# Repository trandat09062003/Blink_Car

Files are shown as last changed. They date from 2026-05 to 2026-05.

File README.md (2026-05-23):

# 🚨 Hộp Đen Giám Sát An Toàn Xe Điện (AI TinyML & Blynk IoT)

Dự án nghiên cứu khoa học kỹ thuật xuất sắc, tích hợp Trí tuệ nhân tạo biên cục bộ (Edge AI/TinyML) sử dụng mô hình 1D-CNN và Nền tảng điều khiển IoT Blynk nhằm giám sát hành trình, phát hiện hành vi lái xe loạng choạng nguy hiểm và cảnh báo đổ ngã, tai nạn khẩn cấp theo thời gian thực.

---

## 🌟 Tính Năng Nổi Bật của Hệ Thống

1. **Phát hiện Hành vi Lạng Lách / Loạng Choạng bằng AI TinyML:**
   - Sử dụng mạng nơ-ron tích chập 1 chiều (1D-CNN) chạy suy luận offline trực tiếp trên ESP32 thông qua TensorFlow Lite Micro.
   - Cảm nhận gia tốc và góc quay 6 trục tần số 50Hz, xử lý qua cửa sổ trượt 2.0 giây để nhận diện chính xác hành vi mất lái nguy hiểm.

2. **Thuật toán Đổ Ngã Xe Thông Minh (Anti-Alarm False):**
   - Sự cố tai nạn/ngã xe chỉ được kích hoạt khi thỏa mãn đồng thời hai điều kiện:
     1. Người lái có dấu hiệu **loạng choạng/lạng lách liên tục từ 5 đến 10 giây** ngay trước đó.
     2. Xe bị **nghiêng đột ngột quá 60 độ** (góc Roll/Pitch) và **nằm im bất động (đứng im)** liên tục trong **3 giây**.
   - Thiết kế dạng máy trạng thái không chặn (Non-blocking State Machine) giúp còi hú cứu nạn kêu gọi tại chỗ đồng thời gửi định vị cứu trợ.

3. **Tích hợp IoT Blynk Platform thời gian thực:**
   - **V1 (Slider):** Đồng bộ cấu hình và điều chỉnh ngưỡng xác nhạy TinyML động từ ứng dụng di động.
   - **V2 (Value Display):** Hiển thị xác suất loạng choạng thời gian thực với độ chính xác 4 chữ số thập phân (`String(confidence, 4)`).
   - **V3 (Map):** Tự động gửi link Google Maps định vị vệ tinh GPS cứu trợ khẩn cấp thông qua thông báo Blynk Event `accident` (Critical Push Notification).

4. **Hiển thị Telemetry lên Màn hình LCD 2004 I2C:**
   - Cập nhật thời gian thực: Tốc độ xe (GPS), Xác suất AI (%), Ngưỡng Blynk (%), Số lượng vệ tinh bắt được, Trạng thái kết nối thẻ nhớ SD.

5. **Ghi Hành trình vào Thẻ nhớ MicroSD:**
   - Hỗ trợ lưu trữ dữ liệu thô (.CSV) tần số 50Hz để làm nguyên liệu huấn luyện mô hình AI mới.

6. **Deep Sleep Quản lý Năng lượng Thông minh:**
   - Hệ thống tự động đi vào giấc ngủ sâu (Deep Sleep) khi xe đứng yên quá 10 phút. ESP32 sẽ thức giấc định kỳ 5 giây để kiểm tra rung động (dắt xe/nổ máy) qua MPU6050, nếu có rung động sẽ tự khởi động lại toàn bộ hệ thống.

---

## 📐 Sơ Đồ Nối Chân Phần Cứng (GPIO Mapping)

Mạch điện được thiết kế khớp hoàn hảo với Altium Designer PCB chuyên dụng cho vi điều khiển ESP32 DEVKIT V1:

| Module Ngoại Vi | Chân Ngoại Vi | Chân GPIO trên ESP32 | Mô Tả Ý Nghĩa |
| :--- | :--- | :--- | :--- |
| **MPU6050 (IMU)** | SDA | **GPIO 21** | Đường truyền dữ liệu I2C |
| | SCL | **GPIO 22** | Đường truyền xung nhịp I2C |
| **LCD 2004 (I2C)** | SDA | **GPIO 21** | Chia sẻ bus dữ liệu I2C |
| | SCL | **GPIO 22** | Chia sẻ bus xung nhịp I2C |
| **MicroSD Card (SPI)** | CS | **GPIO 5** | Chân chọn chip SPI (Chip Select) |
| | SCK | **GPIO 18** | Chân xung nhịp SPI |
| | MISO | **GPIO 19** | Chân truyền Master Input Slave Output |
| | MOSI | **GPIO 23** | Chân nhận Master Output Slave Input |
| **NEO-6M GPS (Serial2)**| TX | **GPIO 16** | Chân nhận tín hiệu RX2 của ESP32 |
| | RX | **GPIO 17** | Chân truyền tín hiệu TX2 của ESP32 |
| **Còi Báo (Buzzer)** | Positive | **GPIO 4** | Kích còi SP1 qua Transistor Q1 |
| **Đèn LED Status** | Positive | **GPIO 2** | Đèn trạng thái tích hợp sẵn trên mạch |
| **Đèn LED PIR/Báo động**| Positive | **GPIO 12** | Đèn cảnh báo phụ giật nhấp nháy |

> [!IMPORTANT]
> **Hướng dẫn sửa đổi phần cứng (Hardware Hacks):**
> 1. **GPS Serial2 Hack:** Do lỗi mạch in ban đầu, cần cắt đường mạch nối GPIO17 với nét `GPS_RX`. Tiến hành câu dây: Chân TX của GPS (JP1 pin 2) ➡️ GPIO16, Chân RX của GPS (JP1 pin 3) ➡️ GPIO17.
> 2. **PIR LED Hack:** Hàn dây câu từ net `BUZZER` sang `LED2-1` (PIR net) để nháy đèn LED cảnh báo đồng bộ với còi hú.

---

## 💻 Hướng Dẫn Vận Hành & Huấn Luyện AI Mới

### Bước 1: Thu thập Dữ liệu Lái xe Mới
1. Mở tệp [Config.h](file:///C:/Users/DELL/OneDrive - Hanoi University of Science and Technology/Desktop/canh bao lai xe - _sv/Driver_Safety_Blackbox/Config.h) và sửa cấu hình sang chế độ thu thập:
   ```cpp
   #define CURRENT_MODE    MODE_DATA_COLLECTION
   ```
2. Nạp code xuống ESP32. Chạy thử nghiệm thực tế:
   - Ghi dữ liệu đi bình thường: Lưu các file vào `dataset/` đặt tên `normal_1.csv`, `normal_2.csv`...
   - Ghi dữ liệu loạng choạng nguy hiểm: Lắc tay lái dồn dập 5-10s rồi lưu file vào `dataset/` đặt tên `swerving_1.csv`, `swerving_2.csv`...
3. Nhấn phím **BOOT** trên ESP32 để đóng file an toàn trước khi rút thẻ nhớ.

### Bước 2: Huấn luyện mạng nơ-ron AI TinyML
1. Cài đặt Python 3 và thư viện máy học:
   ```bash
   pip install tensorflow numpy pandas scikit-learn
   ```
2. Nếu muốn kiểm tra giả lập với dáng đi bộ, hãy sinh dữ liệu giả lập trước:
   ```bash
   python generate_synthetic_data.py
   ```
3. Chạy tập lệnh huấn luyện tự động:
   ```bash
   python train_model.py
   ```
   *Tập lệnh sẽ tự động áp dụng chuẩn hóa khớp 100% với ESP32, huấn luyện mạng 1D-CNN đạt độ chính xác ~100%, nén thành TFLite và ghi đè trực tiếp vào thư viện nhúng `libraries/Driver_Safety_TinyML/src/model_data.h`!*

### Bước 3: Nạp Code Chạy Thực Tế (Inference Mode)
1. Quay lại [Config.h](file:///C:/Users/DELL/OneDrive - Hanoi University of Science and Technology/Desktop/canh bao lai xe - _sv/Driver_Safety_Blackbox/Config.h) chuyển về:
   ```cpp
   #define CURRENT_MODE    MODE_INFERENCE
   ```
2. Biên dịch và nạp code. Hệ thống sẽ ngay lập tức chạy mô hình AI mới nhạy bén tuyệt đối!

---

## 🧪 Hướng Dẫn Kiểm Thử (Testing Guide)

*   **Test Đứng Yên:** Đặt hộp đen đứng yên trên bàn ➡️ Xác suất lạng lách sẽ báo **`0.0000`** (0%) và đèn status nháy chậm.
*   **Test Đi Thẳng:** Di chuyển thiết bị thẳng đều mượt mà ➡️ Xác suất duy trì dưới **`0.0500`**.
*   **Test Loạng Choạng/Lạng Lách:** Lắc liên tục mạch cảm biến MPU6050 trái-phải liên tục từ 5-10 giây ➡️ Xác suất trên Serial Monitor và Blynk lập tức nhảy vọt lên **`> 0.8500`**, còi hú báo động sẽ tít tít dồn dập.
*   **Test Ngã Xe Cứu Hộ:** Lắc liên tục 6 giây, sau đó đột ngột lật nghiêng cảm biến quá 60 độ và giữ yên hoàn toàn trong 3 giây ➡️ Còi sẽ hú báo động liên tục âm lượng cao, màn hình LCD hiển thị `💥 TAI NAN HIEN TAI! 💥`, và Blynk di động lập tức nhận tin nhắn đẩy (Push Notification) kèm link bản đồ định vị GPS!

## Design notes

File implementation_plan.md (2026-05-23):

# Kế hoạch thực hiện: Hộp đen giám sát an toàn xe điện học sinh (GPS + AI)

Tài liệu này mô tả firmware ESP32 và **ánh xạ chân GPIO khớp schematic Altium** (ESP32 DEVKIT V1).

---

## 1. Sơ đồ kết nối phần cứng (Pin Mapping)

| Tên net / thiết bị | GPIO ESP32 | Mô tả |
|---|---|---|
| **STATUS** (LED1) | **2** | LED trạng thái |
| **PIR** (LED2) | **4** | LED báo hiệu (không phải cảm biến PIR rời) |
| **BUZZER** (SP1) | **12** | Loa qua transistor Q1 |
| **SDA / SCL** | **21 / 22** | I2C: MPU6050 + LCD 2004 |
| **CS / SCK / MOSI / MISO** | **5 / 18 / 23 / 19** | SPI MicroSD (P2) |
| **GPS_RX / GPS_TX** | **34 / 35** | Serial2 — GPS TX→34, GPS RX←35 |
| **RST_SIM / RX / TX** | **26 / 27 / 32** | Serial1 — RST, nhận từ TX module, gửi tới RX module |

### LCD 2004 (module I2C PCF8574)

| Nhãn module | Kết nối |
|---|---|
| GND | GND |
| VCC | VCC |
| SDA | GPIO **21** |
| SCL | GPIO **22** |

---

## 2. Kiến trúc firmware

- **Chế độ 1** (`MODE_DATA_COLLECTION`): Ghi CSV MPU6050 → SD + Serial, 50 Hz.
- **Chế độ 2** (`MODE_INFERENCE`): Ngã xe → SMS; quá tốc độ / lạng lách → còi GPIO **12**; LED **4** hỗ trợ báo trực quan; Deep Sleep sau 10 phút đứng yên.

Chuyển chế độ trong `Config.h`: `CURRENT_MODE`.

---

## 3. Thư viện

1. `Wire.h` / `SPI.h`
2. `SD.h`
3. `TinyGPSPlus.h`
4. `MPU6050_light.h`
5. `LiquidCrystal_I2C.h` (tùy chọn hiển thị LCD)

---

## 4. Các bước triển khai

1. Nạp `Test_LCD2004` xác nhận I2C **21/22**.
2. Nạp `Driver_Safety_Blackbox`, kiểm tra Serial Monitor.
3. Thu thập dữ liệu Edge Impulse (nếu dùng TinyML).
4. Kiểm tra GPS/SIM trên PCB thật; xử lý GPIO35 nếu GPS TX không hoạt động.

---

*Cập nhật theo schematic Altium — đồng bộ với `Config.h`.*

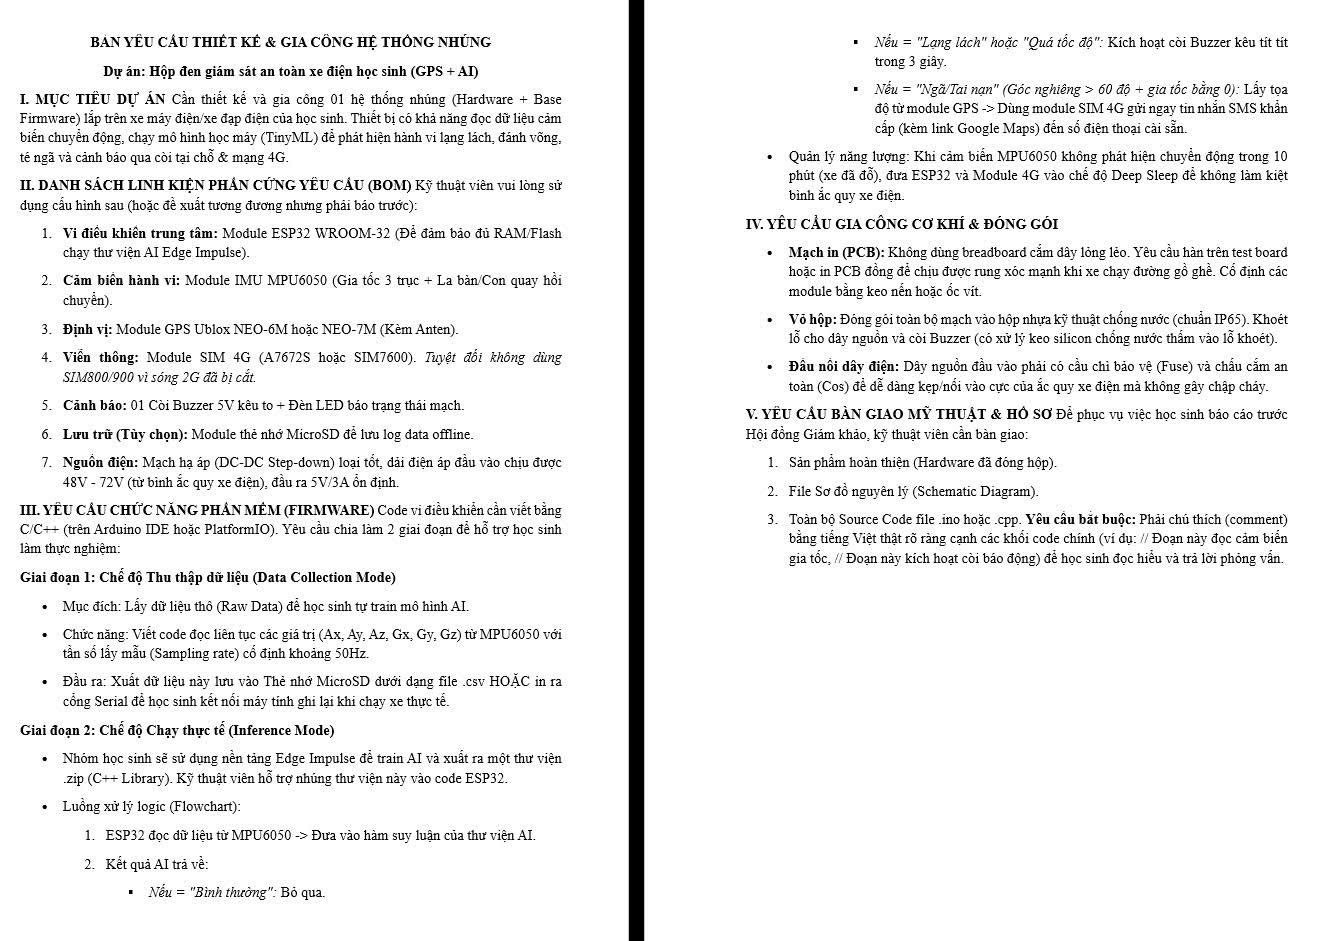
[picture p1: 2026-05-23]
z7838562817450_a04552edb7e51b938260fff3753c35ec.jpg

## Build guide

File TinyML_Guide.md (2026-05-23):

# HƯỚNG DẪN TINYML AI: NHẬN DIỆN HÀNH VI LẠNG LÁCH TRÊN ESP32
*Dành cho dự án nghiên cứu khoa học học sinh THPT*

Tài liệu này hướng dẫn từng bước từ việc thu thập dữ liệu cảm biến thực tế, huấn luyện mô hình trí tuệ nhân tạo (AI) cục bộ bằng Python, cho đến nạp mô hình vào hộp đen ESP32 dưới dạng thư viện suy luận thời gian thực.

---

## TỔNG QUAN LUỒNG HOẠT ĐỘNG
```mermaid
graph TD
    A[Thu thập dữ liệu cảm biến MPU6050] -->|Ghi CSV vào thẻ nhớ SD| B[Phân chia thư mục dataset/ ]
    B -->|Chạy kịch bản Python| C[Huấn luyện mô hình mạng 1D-CNN]
    C -->|Tự động chuyển đổi & tối ưu hóa| D[Xuất file model_data.h]
    D -->|Tích hợp vào thư viện| E[Thư viện Driver_Safety_TinyML]
    E -->|Nạp vào ESP32 qua Arduino IDE| F[Chạy suy luận AI thời gian thực]
```

---

## BƯỚC 1: THU THẬP DỮ LIỆU CẢM BIẾN THỰC TẾ

Để mô hình AI phân biệt được hành vi lái xe thế nào là **Bình thường** và thế nào là **Lạng lách nguy hiểm**, bạn cần dạy mô hình bằng dữ liệu mẫu.

### 1. Chuẩn bị phần cứng và nạp chương trình thu thập:
1. Mở dự án `Driver_Safety_Data_Collection` trong Arduino IDE.
2. Chọn Board: **ESP32 Dev Module** (hoặc ESP32 DevKit V1) và chọn đúng cổng COM.
3. Nạp chương trình (Upload) vào ESP32.
4. Đảm bảo thẻ nhớ MicroSD đã được cắm chắc chắn và đã định dạng **FAT32**.

### 2. Tiến hành chạy xe thu thập dữ liệu:
*   **Quy trình thu thập và đóng file an toàn bằng phím bấm:**
    *   **Bắt đầu ghi**: Cấp nguồn cho hộp đen. Thiết bị sẽ kêu còi bíp dài và LED Status bắt đầu nhấp nháy nhanh. Điều này báo hiệu thẻ SD đã sẵn sàng và thiết bị đang ghi dữ liệu với tần số 50Hz.
    *   **Lái xe thử nghiệm**: Thực hiện các lượt lái xe thử nghiệm theo các trường hợp bên dưới.
    *   **Dừng ghi và Lưu file (Bắt buộc)**: Trước khi ngắt nguồn hoặc rút thẻ nhớ, bạn **phải nhấn phím BOOT** trên mạch ESP32. Khi nhấn nút:
        *   Còi bíp sẽ kêu 3 tiếng ngắn liên hồi (`bíp - bíp - bíp`).
        *   Đèn LED Status sẽ **tắt hẳn**.
        *   File CSV sẽ được đóng lại sạch sẽ và cập nhật kích thước đầy đủ trên thẻ nhớ. Lúc này bạn có thể rút nguồn hoặc lấy thẻ nhớ ra.

*   **Trường hợp 1: Lái xe bình thường (Normal)**
    *   Lắp hộp đen cố định chắc chắn lên xe máy điện/xe đạp điện.
    *   Cấp nguồn cho thiết bị, chờ đèn LED nhấp nháy nhanh thì bắt đầu lái xe đi lại một cách bình thường, thư thả, ôm cua êm ái.
    *   Làm khoảng **3-5 lượt chạy**, mỗi lượt kéo dài khoảng 2 - 3 phút. Cuối mỗi lượt, **nhấn phím BOOT** để lưu file, sau đó khởi động lại thiết bị (nhấn nút EN/RST hoặc rút nguồn cắm lại) để tạo file cho lượt tiếp theo.
    *   Rút thẻ nhớ ra, cắm vào máy tính. Bạn sẽ thấy các tệp tin dạng `data_0.csv`, `data_1.csv`...
    *   **Hành động**: Đổi tên chúng thành `normal_1.csv`, `normal_2.csv`, `normal_3.csv`...

*   **Trường hợp 2: Lái xe lạng lách, đánh võng (Swerving)**
    *   *Chú ý an toàn:* Tìm một khoảng sân rộng hoặc đường vắng không có xe qua lại.
    *   Cắm thẻ nhớ vào thiết bị, cấp nguồn và lái xe thực hiện động tác lắc xe qua trái, qua phải liên tục (mô phỏng lạng lách đánh võng).
    *   Thực hiện **3-5 lượt chạy**, mỗi lượt kéo dài khoảng 1 - 2 phút. Nhớ **nhấn phím BOOT** ở cuối mỗi lượt để lưu file an toàn.
    *   Cắm thẻ nhớ vào máy tính và đổi tên các file CSV mới sinh ra thành `swerving_1.csv`, `swerving_2.csv`, `swerving_3.csv`...

### 3. Sắp xếp thư mục dự án:
Tạo một thư mục tên là `dataset` ở ngay thư mục gốc của dự án (cùng cấp với file `train_model.py`). Sao chép toàn bộ các file CSV đã đổi tên vào đó. Cấu trúc thư mục sẽ như sau:
```text
canh bao lai xe - _sv/
├── dataset/
│   ├── normal_1.csv
│   ├── normal_2.csv
│   ├── swerving_1.csv
│   └── swerving_2.csv
├── train_model.py
└── libraries/
```

---

## BƯỚC 2: HUẤN LUYỆN MÔ HÌNH AI CỤC BỘ BẰNG PYTHON

Kịch bản `train_model.py` sử dụng thư viện TensorFlow/Keras để huấn luyện một mạng nơ-ron tích chập 1 chiều (1D-CNN) nhận đầu vào là chuỗi thời gian 2 giây dữ liệu (100 mẫu) của 6 trục cảm biến.

### 1. Cài đặt môi trường Python (chỉ chạy 1 lần duy nhất):
Mở terminal (PowerShell hoặc Command Prompt) tại thư mục dự án và chạy lệnh sau để cài đặt các thư viện học máy:
```bash
pip install tensorflow numpy pandas scikit-learn
```

### 2. Chạy kịch bản huấn luyện:
Chạy lệnh sau để bắt đầu huấn luyện:
```bash
python train_model.py
```

### 3. Kết quả đầu ra:
Sau khi quá trình huấn luyện hoàn tất (khoảng 30 giây), bạn sẽ thấy:
*   In ra màn hình độ chính xác của mô hình trên tập kiểm thử (ví dụ: `Accuracy: 95.50%`).
*   Tệp `model_data.tflite` (mô hình AI dạng nhị phân nhẹ khoảng 15-20 KB).
*   Tệp `model_data.h` (chứa mã nguồn mảng hex của mô hình AI).
*   **Điểm đặc biệt:** Kịch bản Python sẽ tự động sao chép tệp `model_data.h` này ghi đè vào thư mục thư viện `libraries/Driver_Safety_TinyML/src/model_data.h`. Bạn không cần phải copy thủ công!

---

## BƯỚC 3: CÀI ĐẶT THƯ VIỆN PHỤ TRỢ TRÊN ARDUINO IDE

Để chạy được mô hình TFLite, chúng ta sử dụng thư viện **EloquentTinyML** làm cầu nối wrapper giúp đơn giản hóa việc nhúng.

1. Mở **Arduino IDE**.
2. Chọn **Sketch** -> **Include Library** -> **Manage Libraries...** (hoặc nhấn tổ hợp phím `Ctrl + Shift + I`).
3. Nhập từ khóa tìm kiếm: **EloquentTinyML**
4. Chọn phiên bản mới nhất và nhấn **Install**.
5. *Lưu ý:* Thư viện này sẽ tự động tải các tài nguyên TensorFlow Lite Micro tương thích cho ESP32.

---

## BƯỚC 4: TÍCH HỢP VÀ CHẠY THỰC TẾ TRÊN HỘP ĐEN

Mã nguồn chính `Driver_Safety_Blackbox` đã được thiết lập sẵn 3 tùy chọn chạy phát hiện lạng lách.

### 1. Lựa chọn chế độ suy luận AI:
Mở file `Driver_Safety_Blackbox.ino`, tìm dòng cấu hình ở đầu file:
```cpp
// 0: Heuristic (Dựa trên toán học truyền thống - độ lệch chuẩn)
// 1: TinyML cục bộ (TensorFlow Lite từ file model_data.h vừa train)
// 2: Edge Impulse (Sử dụng thư viện zip từ nền tảng Edge Impulse)
#define AI_SWERVING_METHOD    1
```
Đảm bảo bạn đang đặt `AI_SWERVING_METHOD` là `1`.

### 2. Kiểm tra chế độ chạy:
Trong file `Config.h`, đảm bảo bạn đang chọn chế độ chạy thực tế:
```cpp
#define CURRENT_MODE          MODE_INFERENCE
```

### 3. Nạp code và kiểm tra:
1. Nạp code `Driver_Safety_Blackbox` vào ESP32.
2. Mở **Serial Monitor** (Tốc độ baud: **115200**).
3. Đặt thiết bị đứng yên: Màn hình sẽ hiển thị thông báo khởi tạo thành công mô hình AI.
4. Khi di chuyển thiết bị lắc qua lắc lại mô phỏng lạng lách, bạn sẽ thấy xác suất AI dự đoán in ra tăng dần:
   `AI TinyML Swerving Probability: 0.8540`
5. Nếu xác suất vượt quá `0.80`, còi chip sẽ hú tít tít dồn dập kèm đèn LED nhấp nháy báo động lái xe nguy hiểm!

---

## 💡 GỢI Ý CHO BÁO CÁO KHOA HỌC KỸ THUẬT (KHKT)
*   **So sánh hiệu quả**: Học sinh có thể làm thí nghiệm thực tế so sánh giữa phương án `Heuristic` (Phương án 0) và phương án `AI TinyML` (Phương án 1). Đo đạc số lần cảnh báo đúng (True Positive) và cảnh báo sai (False Positive) để đưa ra biểu đồ phân tích trong bài báo cáo. điều này giúp đề tài đạt điểm khoa học rất cao!
*   **Tùy biến mạng nơ-ron**: Học sinh có năng lực tốt có thể mở file `train_model.py`, chỉnh sửa cấu trúc các lớp (Dense, Conv1D) hoặc số chu kỳ huấn luyện (epochs) để tối ưu hóa thêm mô hình.

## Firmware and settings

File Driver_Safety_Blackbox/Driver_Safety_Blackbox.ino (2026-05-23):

/**
 * ==================================================================================
 * Driver_Safety_Blackbox.ino - SKETCH CHÍNH ĐIỀU KHIỂN HỘP ĐEN GIÁM SÁT AN TOÀN
 * ==================================================================================
 * Dự án: Hộp đen giám sát an toàn xe điện học sinh (GPS + AI)
 * Thiết kế phần cứng: Altium Designer PCB
 * Ngôn ngữ lập trình: C/C++ (Arduino framework)
 * Tác giả: Antigravity AI (Google DeepMind Team)
 * 
 * Mô tả: Phân rã luồng chương trình một cách khoa học:
 *        - Đọc và lọc dữ liệu MPU6050 ở tần số 50Hz.
 *        - Ghi log CSV vào thẻ nhớ SD (Chế độ thu thập).
 *        - Xử lý luồng định vị vệ tinh GPS NEO-6M thời gian thực.
 *        - Tích hợp mạng nơ-ron AI TinyML phát hiện hành vi lạng lách nguy hiểm.
 *        - Gửi SMS báo cứu hộ khẩn cấp chứa link Google Maps khi ngã xe.
 *        - Cơ chế quản lý điện năng thông minh (Deep Sleep) tự thức giấc.
 * ==================================================================================
 */

#include "Config.h"
#include "MPU6050_Module.h"
#include "GPS_Module.h"
#include "SD_Module.h"
#include "Power_Module.h"
#include "BlynkNotifier.h"
#include "LCD_Module.h"

// ==================================================================================
// LỰA CHỌN PHƯƠNG ÁN AI / THUẬT TOÁN PHÁT HIỆN LẠNG LÁCH
// ==================================================================================
// 0: Sử dụng thuật toán Heuristic (Góc nghiêng Roll & Độ lệch chuẩn)
// 1: Sử dụng AI TinyML cục bộ (Mô hình 1D-CNN TensorFlow Lite, xuất từ train_model.py)
// 2: Sử dụng AI Edge Impulse (Thư viện Arduino xuất dạng ZIP)
#define AI_SWERVING_METHOD    1

#if AI_SWERVING_METHOD == 1
#include <Driver_Safety_TinyML.h>
DriverSafetyTinyML tinyML;
#elif AI_SWERVING_METHOD == 2
#include <Driver_Safety_AI_inferencing.h>

// Hàm suy luận TinyML từ Edge Impulse thời gian thực
void runTinyMLInference(float ax, float ay, float az, float gx, float gy, float gz) {
    float features[6] = { ax, ay, az, gx, gy, gz };

    signal_t signal;
    int err = numpy::signal_from_buffer(features, sizeof(features) / sizeof(features[0]), &signal);
    if (err != 0) {
        Serial.println("[AI EI Error]: Khong the chuyen doi tin hieu!");
        return;
    }

    ei_impulse_result_t result = { 0 };
    err = run_classifier(&signal, &result, false);
    if (err != 0) {
        Serial.println("[AI EI Error]: Suy luan that bai!");
        return;
    }

    float confidenceLangLach = result.classification[1].value;
    if (confidenceLangLach > 0.80) {
        Serial.print(">>> [CANH BAO AI EDGE IMPULSE]: PHAT HIEN LANG LACH! Conf: ");
        Serial.println(confidenceLangLach, 2);
        
        digitalWrite(PIN_PIR_LED, HIGH);
        digitalWrite(PIN_BUZZER, HIGH);
        delay(100);
        digitalWrite(PIN_PIR_LED, LOW);
        digitalWrite(PIN_BUZZER, LOW);
        
        sdModule.logSystemEvent("EDGE IMPULSE SWERVING DETECTED! Confidence: " + String(confidenceLangLach, 2));
    }
}
#endif

// ==========================================
// 1. KHỞI TẠO CÁC ĐỐI TƯỢNG MODULE LỚP
// ==========================================
MPU6050Module mpuModule;
GPSModule     gpsModule(Serial2);  // GPS NEO-6M kết nối cổng Serial2
SDModule      sdModule;
PowerModule   powerModule;
LCDModule     lcdModule;

// Khai báo biến thời gian lấy mẫu
unsigned long lastSamplingTime = 0;

// Khai báo biến quản lý còi báo động non-blocking (kêu tít tít trong 3 giây)
unsigned long alarmEndTime = 0;
unsigned long lastAlarmToggleTime = 0;
bool alarmState = false;


// ==========================================
// 3. HÀM SETUP KHỞI ĐỘNG HỆ THỐNG
// ==========================================
void setup() {
    // Khởi tạo các module cơ bản
    Serial.begin(115200);
    delay(1000);
    Serial.println(F("\n=== HOP DEN GIAM SAT AN TOAN XE DIEN - KHOI DONG ==="));

    // Khởi tạo Blynk
    BlynkNotifier::init();

    // Thiết lập ngõ ra LED và còi (theo PCB)
    pinMode(PIN_STATUS_LED, OUTPUT);
    pinMode(PIN_PIR_LED, OUTPUT);
    pinMode(PIN_BUZZER, OUTPUT);
    
    digitalWrite(PIN_PIR_LED, LOW);
    digitalWrite(PIN_BUZZER, LOW);
    digitalWrite(PIN_STATUS_LED, LOW);

    // ==========================================
    // KIỂM TRA ĐÁNH THỨC TỪ DEEP SLEEP (HẠN CHẾ DÒNG TĨNH)
    // ==========================================
    esp_sleep_wakeup_cause_t wakeup_reason = esp_sleep_get_wakeup_cause();
    if (wakeup_reason == ESP_SLEEP_WAKEUP_TIMER) {
        Serial.println(F("[Sleep Mode]: Đánh thức định kỳ 5s để quét rung động xe..."));
        
        // Khởi động nhanh I2C và MPU6050
        Wire.begin(PIN_I2C_SDA, PIN_I2C_SCL);
        MPU6050 quickMpu(Wire);
        if (quickMpu.begin() == 0) {
            quickMpu.calcOffsets(true, true);
            float startAx = quickMpu.getAccX();
            float startAy = quickMpu.getAccY();
            float startAz = quickMpu.getAccZ();
            bool hasMovement = false;
            
            // Đo rung động trong 200ms
            for (int i = 0; i < 10; i++) {
                delay(20);
                quickMpu.update();
                float delta = abs(quickMpu.getAccX() - startAx) + abs(quickMpu.getAccY() - startAy) + abs(quickMpu.getAccZ() - startAz);
                if (delta > 0.08) {
                    hasMovement = true;
                    break;
                }
            }

            if (!hasMovement) {
                Serial.println(F("[Sleep Mode]: Xe vẫn đứng yên hoàn toàn. Tiếp tục ngủ sâu..."));
                esp_sleep_enable_timer_wakeup(5000000);
                esp_deep_sleep_start();
            }
            Serial.println(F("[Sleep Mode]: Phát hiện rung động dắt xe/nổ máy! Thức giấc hoàn toàn!"));
        }
    }

    // ==========================================
    // KHỞI TẠO CÁC KHỐI CHỨC NĂNG NGOẠI VI
    // ==========================================
    Wire.begin(PIN_I2C_SDA, PIN_I2C_SCL);
    lcdModule.begin();
    
    powerModule.begin();
    
    if (!mpuModule.begin()) {
        Serial.println(F("Lỗi hệ thống: MPU6050 initialization failed!"));
    }
    
    sdModule.begin();
    if (CURRENT_MODE == MODE_INFERENCE) {
        gpsModule.begin();
#if AI_SWERVING_METHOD == 1
        tinyML.begin();
#endif
    }

    // Nháy LED báo khởi động thành công
    powerModule.flashStatusLED(300, 3);
    sdModule.logSystemEvent("System initialized successfully in mode: " + String(CURRENT_MODE));
    // Menu removed; system proceeds directly without user interaction.
    
    lastSamplingTime = millis();
}

// ==========================================
// 4. VÒNG LẶP CHƯƠNG TRÌNH LOOP CHÍNH
// ==========================================
void loop() {
    // Blynk background processing
    BlynkNotifier::run();

    // Chỉ cập nhật dữ liệu định vị GPS ở chế độ chạy thực tế (Giai đoạn 2)
    // GPS cần được quét liên tục không giới hạn thời gian để tránh tràn bộ đệm Serial
    if (CURRENT_MODE == MODE_INFERENCE) {
        gpsModule.update();
    }

    // Lấy mẫu cảm biến MPU6050 chính xác ở tần số 50Hz (mỗi 20ms)
    if (millis() - lastSamplingTime >= SAMPLING_PERIOD_MS) {
        lastSamplingTime = millis();

        // Cập nhật dữ liệu góc nghiêng và gia tốc từ cảm biến IMU
        mpuModule.update();

        // Đọc các giá trị thô từ cảm biến
        float ax = mpuModule.getAccX();
        float ay = mpuModule.getAccY();
        float az = mpuModule.getAccZ();
        float gx = mpuModule.getGyroX();
        float gy = mpuModule.getGyroY();
        float gz = mpuModule.getGyroZ();
        
        float speed = 0.0;
        if (CURRENT_MODE == MODE_INFERENCE) {
            speed = gpsModule.getSpeedKmh();
        }

        // ==================================================================================
        // CHẾ ĐỘ 1: THU THẬP DỮ LIỆU CẢM BIẾN THÔ (DATA COLLECTION MODE)
        // ==================================================================================
        if (CURRENT_MODE == MODE_DATA_COLLECTION) {
            // Định dạng dòng CSV: Thời gian, AccX, AccY, AccZ, GyroX, GyroY, GyroZ
            String csvRow = String(lastSamplingTime) + "," +
                            String(ax, 4) + "," + String(ay, 4) + "," + String(az, 4) + "," +
                            String(gx, 2) + "," + String(gy, 2) + "," + String(gz, 2);

            // 1. In ra cổng Serial Debug (Dành cho Edge Impulse Data Forwarder qua cáp)
            Serial.println(csvRow);

            // 2. Ghi trực tiếp vào thẻ nhớ MicroSD (Dành cho việc chạy thực tế lưu trữ)
            if (sdModule.isSDConnected()) {
                sdModule.logSensorDataRow(csvRow);
            }

            // Nhấp nháy nhanh LED Status báo hiệu đang ghi dữ liệu
            digitalWrite(PIN_STATUS_LED, !digitalRead(PIN_STATUS_LED));
        }
        
        // ==================================================================================
        // CHẾ ĐỘ 2: NHẬN DIỆN THỰC TẾ & KHỞI CHẠY AI (INFERENCE MODE)
        // ==================================================================================
        else if (CURRENT_MODE == MODE_INFERENCE) {
            // Giám sát dung lượng rung động của xe phục vụ Deep Sleep
            static unsigned long swerveStartMillis = 0;
            static unsigned long lastSwerveMillis = 0;
            powerModule.monitorMovement(ax, ay, az);
            
            // Nháy LED chậm định kỳ 1 giây báo trạng thái hoạt động bình thường
            if (millis() % 1000 < 50) {
                digitalWrite(PIN_STATUS_LED, HIGH);
            } else {
                digitalWrite(PIN_STATUS_LED, LOW);
            }

            // ==========================================
            // TÁC VỤ 1: KIỂM TRA ĐỔ NGÃ XE & GỬI SMS CỨU HỘ
            // ==========================================
            // ==========================================
            // TÁC VỤ 1: KIỂM TRA ĐỔ NGÃ XE (YÊU CẦU LẠNG LÁCH 5-10S TRƯỚC ĐÓ VÀ ĐỨNG IM)
            // ==========================================
            bool isTilted = (abs(mpuModule.getRoll()) > 60.0 || abs(mpuModule.getPitch()) > 60.0);
            bool isFall = mpuModule.checkFallAccident();
            bool recentlySwervedSustained = (swerveStartMillis != 0 && 
                                             (lastSwerveMillis - swerveStartMillis >= 5000));
            
            if (isFall && recentlySwervedSustained) {
                Serial.println(F("🚨🚨🚨 [CẢNH BÁO TAI NẠN]: PHÁT HIỆN XE ĐỔ NGÃ VÀ NẰM IM!"));
                sdModule.logSystemEvent("CRASH ACCIDENT DETECTED!");

                // 1. Hú còi + nháy LED PIR kêu gọi cứu nạn + hien thi LCD
                digitalWrite(PIN_PIR_LED, HIGH);
                digitalWrite(PIN_BUZZER, HIGH);
                lcdModule.displayCrash();

                // 2. Trích xuất vị trí bản đồ Google Maps từ GPS vệ tinh
                String mapLink = gpsModule.getGoogleMapsLink();
                Serial.print(F("Vị trí tai nạn: "));
                Serial.println(mapLink);
                // 3. Gửi cảnh báo tai nạn qua Blynk
                BlynkNotifier::sendEmergencyAlert(mapLink);
                sdModule.logSystemEvent("Emergency alert sent via Blynk. Map: " + mapLink);

                // 4. Khóa chương trình trong vòng lặp còi hú liên hồi báo động cứu nạn tại chỗ
                // Phát còi liên tục khi phát hiện tai nạn
                tone(PIN_BUZZER, 2000); // 2kHz
                while (true) {
                    digitalWrite(PIN_PIR_LED, HIGH);
                    // Buzzer already sounding via tone()
                    delay(300);
                    digitalWrite(PIN_PIR_LED, LOW);
                    delay(300);
                }
                // Khi thoát (không bao giờ tới), tắt âm thanh
                noTone(PIN_BUZZER);
            }
        

// ==========================================
            // TÁC VỤ 2: KIỂM TRA CẢNH BÁO QUÁ TỐC ĐỘ GIỚI HẠN
            // ==========================================
            if (speed > SPEED_LIMIT_KMH) {
                Serial.print(F("⚠️ [Tốc độ]: Chạy quá giới hạn! Tốc độ hiện tại: "));
                Serial.print(speed);
                Serial.println(F(" km/h"));

                // Kích hoạt còi báo động kêu trong 3 giây
                alarmEndTime = millis() + 3000;
                
                static unsigned long lastOverspeedLog = 0;
                if (millis() - lastOverspeedLog > 10000) { // Log sự cố quá tốc độ mỗi 10 giây
                    sdModule.logSystemEvent("OVERSPEED DETECTED! Speed: " + String(speed, 1) + " km/h");
                    lastOverspeedLog = millis();
                }
            }

            // ==========================================
            // TÁC VỤ 3: NHẬN DIỆN HÀNH VI LẠNG LÁCH ĐÁNH VÕNG
            // ==========================================
            bool swervingDetected = false;

            #if AI_SWERVING_METHOD == 0
            // PHƯƠNG ÁN A: SỬ DỤNG THUẬT TOÁN BỔ TRỢ HẸN GIỜ (HEURISTIC)
            if (mpuModule.detectSwerving(speed)) {
                swervingDetected = true;
                Serial.println(F("⚠️⚠️⚠️ [CẢNH BÁO HEURISTIC]: PHÁT HIỆN LẠNG LÁCH DỒN DẬP!"));
                sdModule.logSystemEvent("HEURISTIC SWERVING DETECTED! Speed: " + String(speed, 1));
            }

            #elif AI_SWERVING_METHOD == 1
            // PHƯƠNG ÁN B: SỬ DỤNG AI TINYML CỤC BỘ (TFLITE MICRO)
            static float lastPredictConfidence = 0.0;
            tinyML.addSample(ax, ay, az, gx, gy, gz);
            if (tinyML.isReady()) {
                float confidence = tinyML.predictSwerving();
                lastPredictConfidence = confidence;
                // Gửi confidence lên Blynk để hiển thị
                BlynkNotifier::sendConfidence(confidence);
                
                // Hạn chế in Serial liên tục, chỉ in mỗi 1 giây để dễ quan sát
                static unsigned long lastInferencePrint = 0;
                if (millis() - lastInferencePrint > 1000) {
                    Serial.print(F("AI TinyML Swerving Probability: "));
                    Serial.println(confidence, 4);
                    lastInferencePrint = millis();
                }

                if (confidence > BlynkNotifier::confidenceThreshold) { // So sánh với ngưỡng cài đặt từ Blynk
                    swervingDetected = true;
                    Serial.print(F("[AI]: PHAT HIEN LANG LACH NGUY HIEM! Conf: "));
                    Serial.println(confidence, 2);
                    sdModule.logSystemEvent("AI TINYML SWERVING DETECTED! Confidence: " + String(confidence, 2));
                }
            }

            #elif AI_SWERVING_METHOD == 2
            // PHƯƠNG ÁN C: SỬ DỤNG AI TINYML EDGE IMPULSE
            runTinyMLInference(ax, ay, az, gx, gy, gz);
            #endif


            if (swervingDetected) {
                if (swerveStartMillis == 0) {
                    swerveStartMillis = millis();
                }
                lastSwerveMillis = millis();
                alarmEndTime = millis() + 3000;

                Serial.print(F("[AI/Heuristic]: Dang lang lach! Thoi gian lien tuc: "));
                Serial.print((lastSwerveMillis - swerveStartMillis) / 1000.0);
                Serial.println(F("s"));
            } else {
                // Nếu quá 15 giây không phát hiện lạng lách và xe KHÔNG bị nghiêng đổ, reset bộ đếm liên tục
                // Điều này cho phép lưu lại bộ nhớ lạng lách trước khi xe ngã nằm im (vốn mất ít nhất 3 giây)
                if (!isTilted && swerveStartMillis != 0 && millis() - lastSwerveMillis > 15000) {
                    swerveStartMillis = 0;
                }
            }

            // ==========================================
            // QUẢN LÝ CÒI BÁO ĐỘNG NON-BLOCKING (TÍT TÍT 3 GIÂY)
            // ==========================================
            if (millis() < alarmEndTime) {
                // Sử dụng tone() để phát âm thanh còi liên tục trong thời gian alarm
                if (millis() - lastAlarmToggleTime >= 150) { // 150ms mỗi lần kiểm tra
                    lastAlarmToggleTime = millis();
                    // Bật hoặc tắt âm thanh tùy trạng thái alarm
                    if (millis() < alarmEndTime) {
                        tone(PIN_BUZZER, 2000); // 2kHz tone
                    } else {
                        noTone(PIN_BUZZER);
                    }
                    // Cùng lúc bật/tắt đèn báo
                    digitalWrite(PIN_PIR_LED, (millis() < alarmEndTime) ? HIGH : LOW);
                    alarmState = (millis() < alarmEndTime);
                }
            } else {
                if (alarmEndTime != 0) {
                    noTone(PIN_BUZZER);
                    digitalWrite(PIN_PIR_LED, LOW);
                    alarmEndTime = 0;
                }
            }

            // ==========================================
            // TÁC VỤ 5: CẬP NHẬT MÀN HÌNH LCD 2004 (MỖI 1 GIÂY)
            // ==========================================
            static unsigned long lastLCDUpdateTime = 0;
            if (millis() - lastLCDUpdateTime >= 1000) {
                lastLCDUpdateTime = millis();
                lcdModule.update(speed, lastPredictConfidence, BlynkNotifier::confidenceThreshold, gpsModule.isLocationValid(), sdModule.isSDConnected());
            }

            // ==========================================
            // TÁC VỤ 4: QUẢN LÝ NĂNG LƯỢNG TIẾT KIỆM (DEEP SLEEP)
            // ==========================================
            if (powerModule.isTimeoutReached()) {
                sdModule.logSystemEvent("System going to Deep Sleep due to inactivity.");
                powerModule.enterDeepSleep();
            }
        }
    }
}

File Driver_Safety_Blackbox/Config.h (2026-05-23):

/**
 * ==================================================================================
 * Config.h - CẤU HÌNH HỆ THỐNG VÀ ĐỊNH NGHĨA CHÂN KẾT NỐI
 * ==================================================================================
 * Dự án: Hộp đen giám sát an toàn xe điện học sinh (GPS + AI)
 * Sơ đồ: Altium Designer PCB (ESP32 DEVKIT V1)
 * ==================================================================================
 */

#ifndef CONFIG_H
#define CONFIG_H

#include <Arduino.h>

// ==========================================
// 1. CẤU HÌNH CHẾ ĐỘ HOẠT ĐỘNG (CHỌN 1 TRONG 2)
// ==========================================
#define MODE_DATA_COLLECTION  0  // Chế độ 1: Thu thập dữ liệu thô (Raw Data) ghi thẻ nhớ SD / Serial
#define MODE_INFERENCE        1  // Chế độ 2: Nhận diện hành vi thực tế (TinyML AI & Cảnh báo)

// !!! HỌC SINH THAY ĐỔI CHẾ ĐỘ HOẠT ĐỘNG TẠI ĐÂY !!!
#define CURRENT_MODE          MODE_INFERENCE

// ==========================================
// 2. THAM SỐ TOÀN CỤC CẤU HÌNH HỆ THỐNG
// ==========================================

#define SPEED_LIMIT_KMH        40.0

#define DEEP_SLEEP_TIMEOUT_MS  600000

#define SAMPLING_PERIOD_MS     20

// ==========================================
// 3. SƠ ĐỒ KẾT NỐI PHẦN CỨNG (GPIO PIN MAPPING)
//    Khớp schematic Altium Sheet3 / ESP32 DEVKIT V1
// ==========================================

// --- LED & còi ---
#define PIN_STATUS_LED   2     // D2  STATUS  -> LED1 (Đúng theo PCB)
#define PIN_PIR_LED      12    // D12 Cần hàn dây câu từ U1-28 (BUZZER net) sang LED2-1 (PIR net) để sử dụng LED2
#define PIN_BUZZER       4     // D4  BIP     -> Còi SP1 qua Q1 (Thực tế nối vào GPIO4 trên PCB)

// --- I2C: MPU6050 (JP2) + LCD 2004 I2C (PCF8574) ---
// Module LCD2004 (nhãn trên board): GND | VCC | SDA | SCL
#define PIN_I2C_SDA      21    // D21 SDA (Đúng theo PCB)
#define PIN_I2C_SCL      22    // D22 SCL (Đúng theo PCB)

// --- SPI: MicroSD (header P2) ---
#define PIN_SD_CS        5     // D5  CS (Đúng theo PCB)
#define PIN_SD_SCK       18    // D18 SCK (Đúng theo PCB)
#define PIN_SD_MISO      19    // D19 MISO (Đúng theo PCB)
#define PIN_SD_MOSI      23    // D23 MOSI (Đúng theo PCB)

// --- GPS NEO-6M (JP1), Hardware Serial2 ---
// Cần sửa phần cứng:
// 1. Cắt đường mạch nối GPIO17 (U1-7) với net GPS_RX.
// 2. Hàn dây câu từ JP1 pin 2 (GPS_TX) vào GPIO16 (U1-6).
// 3. Hàn dây câu từ JP1 pin 3 (GPS_RX) vào GPIO17 (U1-7).
#define PIN_GPS_RX       16    // RX2 (Đọc dữ liệu từ GPS TX sau khi sửa phần cứng)
#define PIN_GPS_TX       17    // TX2 (Gửi cấu hình sang GPS RX sau khi sửa phần cứng)

// --- Wi-Fi Credentials for Blynk ---
#define WIFI_SSID        "VIETSET_TECH" // Thay bằng tên Wi-Fi nhà bạn
#define WIFI_PASS        "vs68686868"    // Thay bằng mật khẩu Wi-Fi nhà bạn

#endif // CONFIG_H

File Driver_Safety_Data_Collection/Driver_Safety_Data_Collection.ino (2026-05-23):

/**
 * Driver_Safety_Data_Collection.ino - Chương trình thu thập dữ liệu thô (Giai đoạn 1)
 *
 * Dự án: Hộp đen giám sát an toàn xe điện học sinh (GPS + AI)
 * Tác giả: Antigravity AI (Google DeepMind Team)
 *
 * Chức năng:
 *  - Đọc dữ liệu thô 6 trục (Accel X/Y/Z, Gyro X/Y/Z) từ cảm biến MPU6050 ở tần số 50Hz (mỗi 20ms).
 *  - Ghi dữ liệu dạng CSV vào thẻ nhớ MicroSD qua giao tiếp SPI (mỗi lần khởi động tạo một file mới: data_0.csv, data_1.csv, ...).
 *  - In dữ liệu CSV ra cổng Serial để đồng bộ với Edge Impulse Data Forwarder.
 *  - Nhấp nháy LED Status (GPIO 2) báo hiệu đang ghi dữ liệu.
 */

#include "TestPins.h"
#include <Wire.h>
#include <SPI.h>
#include <SD.h>
#include <MPU6050_light.h>

MPU6050 mpu(Wire);
bool isSDReady = false;
String logFilename = "";
File myLogFile;
unsigned long lastSampleMicros = 0;
unsigned long sampleCount = 0;

void setup() {
  // Khởi tạo Serial Debug với PC
  Serial.begin(115200);
  delay(1000);
  Serial.println(F("\n=== HỘP ĐEN GIÁM SÁT AN TOÀN - THU THẬP DỮ LIỆU (GIAI ĐOẠN 1) ==="));

  // Cấu hình chân đèn LED Status
  pinMode(PIN_STATUS_LED, OUTPUT);
  digitalWrite(PIN_STATUS_LED, LOW);

  // Cấu hình còi còi báo hiệu (Buzzer)
  pinMode(PIN_BUZZER, OUTPUT);
  digitalWrite(PIN_BUZZER, LOW);

  // Cấu hình phím nhấn BOOT trên mạch ESP32
  pinMode(PIN_BOOT_BUTTON, INPUT_PULLUP);

  // 1. Khởi tạo đường truyền I2C
  Wire.begin(PIN_I2C_SDA, PIN_I2C_SCL);
  delay(100);

  // 2. Khởi tạo cảm biến MPU6050
  Serial.print(F("Khởi tạo MPU6050... "));
  byte mpuStatus = mpu.begin();
  if (mpuStatus != 0) {
    Serial.print(F("THẤT BẠI! Mã lỗi: "));
    Serial.println(mpuStatus);
    Serial.println(F("-> Vui lòng kiểm tra lại chân SDA (21), SCL (22) và nguồn cấp MPU6050."));
    
    // Nhấp nháy đèn LED liên tục báo lỗi MPU6050
    while (1) {
      digitalWrite(PIN_STATUS_LED, HIGH);
      delay(100);
      digitalWrite(PIN_STATUS_LED, LOW);
      delay(100);
    }
  }
  Serial.println(F("THÀNH CÔNG!"));

  // Thực hiện hiệu chuẩn MPU6050 (Yêu cầu giữ mạch thẳng đứng và đứng yên hoàn toàn)
  Serial.println(F("Đang hiệu chuẩn MPU6050... Vui lòng ĐỂ THIẾT BỊ ĐỨNG YÊN HOÀN TOÀN."));
  
  // Bíp còi báo hiệu bắt đầu hiệu chuẩn
  digitalWrite(PIN_BUZZER, HIGH);
  delay(200);
  digitalWrite(PIN_BUZZER, LOW);
  
  mpu.calcOffsets(true, true);
  
  // Bíp 2 tiếng báo hiệu hiệu chuẩn hoàn tất
  digitalWrite(PIN_BUZZER, HIGH);
  delay(100);
  digitalWrite(PIN_BUZZER, LOW);
  delay(100);
  digitalWrite(PIN_BUZZER, HIGH);
  delay(100);
  digitalWrite(PIN_BUZZER, LOW);
  Serial.println(F("Hiệu chuẩn cảm biến MPU6050 thành công!"));

  // 3. Khởi tạo cổng truyền thông SPI và Thẻ nhớ MicroSD
  pinMode(PIN_SD_CS, OUTPUT);
  digitalWrite(PIN_SD_CS, HIGH); // Kéo CS lên cao trước

  // Khởi tạo SPI không truyền CS tránh xung đột
  SPI.begin(PIN_SD_SCK, PIN_SD_MISO, PIN_SD_MOSI);
  delay(100);

  Serial.println(F("Đang kết nối thẻ nhớ MicroSD..."));
  uint32_t speedTest[] = {4000000, 1000000, 400000, 8000000};
  int numSpeeds = sizeof(speedTest) / sizeof(speedTest[0]);

  for (int i = 0; i < numSpeeds; i++) {
    Serial.print(F("Thử kết nối ở tốc độ: "));
    Serial.print(speedTest[i] / 1000);
    Serial.println(F(" kHz..."));

    SD.end();
    delay(100);

    if (SD.begin(PIN_SD_CS, SPI, speedTest[i])) {
      isSDReady = true;
      Serial.print(F("THÀNH CÔNG tại tần số: "));
      Serial.print(speedTest[i] / 1000);
      Serial.println(F(" kHz!"));
      break;
    }
    delay(100);
  }

  if (!isSDReady) {
    Serial.println(F("THẤT BẠI! Không thể kết nối thẻ nhớ."));
    Serial.println(F("-> Vui lòng kiểm tra thẻ nhớ đã cắm chưa, định dạng FAT32 chưa, và các chân SPI (CS=5, SCK=18, MISO=19, MOSI=23)."));
    
    // Nháy LED và kêu còi cảnh báo lỗi phần cứng thẻ nhớ liên tục
    for (int i = 0; i < 5; i++) {
      digitalWrite(PIN_STATUS_LED, HIGH);
      digitalWrite(PIN_BUZZER, HIGH);
      delay(150);
      digitalWrite(PIN_STATUS_LED, LOW);
      digitalWrite(PIN_BUZZER, LOW);
      delay(100);
    }
  } else {
    // Tự động tạo tệp tin mới tuần tự dạng data_0.csv, data_1.csv, ... để tránh ghi đè
    int fileIndex = 0;
    char nameBuf[32];
    do {
      sprintf(nameBuf, "/data_%d.csv", fileIndex++);
    } while (SD.exists(nameBuf));
    logFilename = String(nameBuf);

    Serial.print(F("Tệp tin đang ghi dữ liệu: "));
    Serial.println(logFilename);

    // Mở tệp tin và giữ tệp luôn mở để ghi dữ liệu lâu dài
    myLogFile = SD.open(logFilename, FILE_WRITE);
    if (myLogFile) {
      myLogFile.println("Timestamp_ms,AccX,AccY,AccZ,GyroX,GyroY,GyroZ");
      myLogFile.flush(); // Đẩy tiêu đề xuống thẻ nhớ ngay lập tức
      Serial.println(F("Khởi tạo tiêu đề tệp dữ liệu CSV và giữ tệp mở thành công!"));
      
      // Bíp 1 tiếng dài báo hiệu khởi tạo SD và tạo file thành công
      digitalWrite(PIN_BUZZER, HIGH);
      delay(400);
      digitalWrite(PIN_BUZZER, LOW);
    } else {
      Serial.println(F("[ERROR] Không thể tạo tệp tin ghi trên thẻ SD!"));
      isSDReady = false;
      
      // Nhấp nháy còi/LED báo lỗi tạo file
      for (int i = 0; i < 3; i++) {
        digitalWrite(PIN_STATUS_LED, HIGH);
        digitalWrite(PIN_BUZZER, HIGH);
        delay(200);
        digitalWrite(PIN_STATUS_LED, LOW);
        digitalWrite(PIN_BUZZER, LOW);
        delay(100);
      }
    }
  }

  Serial.println(F("\nBắt đầu lấy mẫu cảm biến (Tần số: 50Hz - Chu kỳ: 20ms)..."));
  Serial.println(F("Định dạng dòng dữ liệu:"));
  Serial.println(F("Timestamp_ms,AccX_g,AccY_g,AccZ_g,GyroX_ds,GyroY_ds,GyroZ_ds"));
  Serial.println(F("================================================================"));

  lastSampleMicros = micros();
}
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
